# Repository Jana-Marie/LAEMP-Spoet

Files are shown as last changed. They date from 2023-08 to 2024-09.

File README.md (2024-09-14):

# LÄMP-Spöt

LÄMP-Spöt is an open source, multi-channel (multi-colour) LED spot that aims to deliver high quality effect-lighting through up to 6 LED-channels with ~10W each. This allows for a broader colour range than just RGB or RGBW, but RGB + non-mixed secondaries (i.e. RGB, Yellow, Cyan, Purple), RGB + Yellow + Whites, a variety of White tones (with degrees of Red, Blue and Green hues) and of course effect channels (i.e. UV, IR). In that, I have assembled various spöts that follow these suggestions, one that features RGBY + UV + IR, RGBY + IR + White and one with three channels of white + UV + IR for plants

<table>
	<tbody>
		<tr>
			<td>
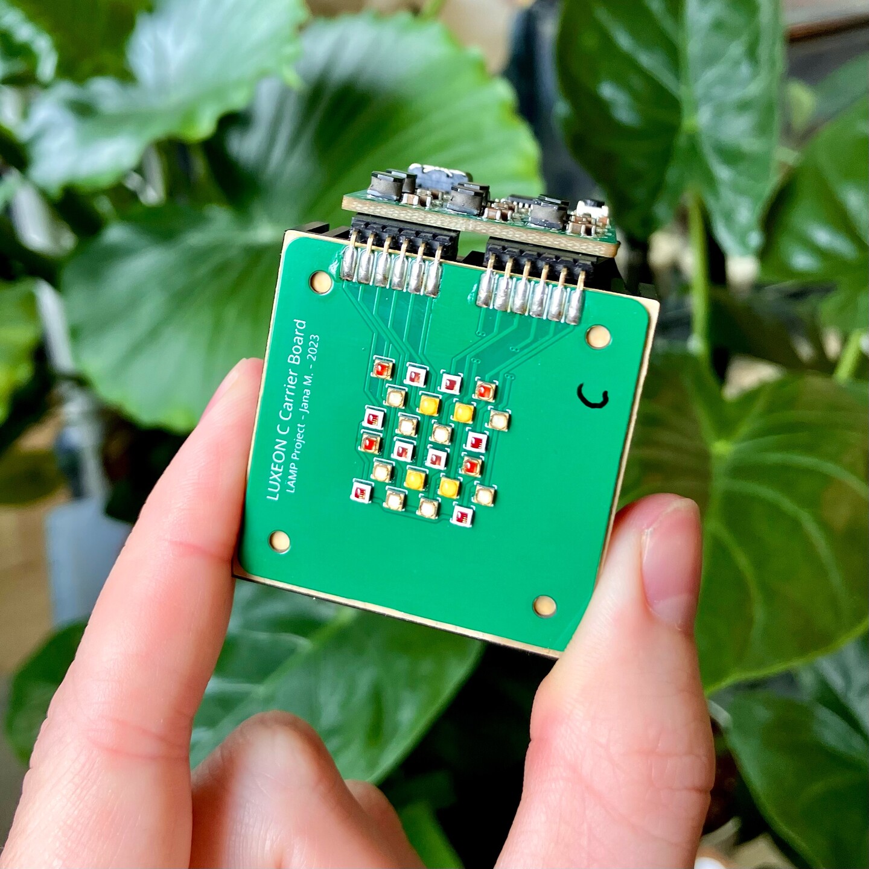
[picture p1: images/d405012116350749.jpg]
				
			</td>
			<td>
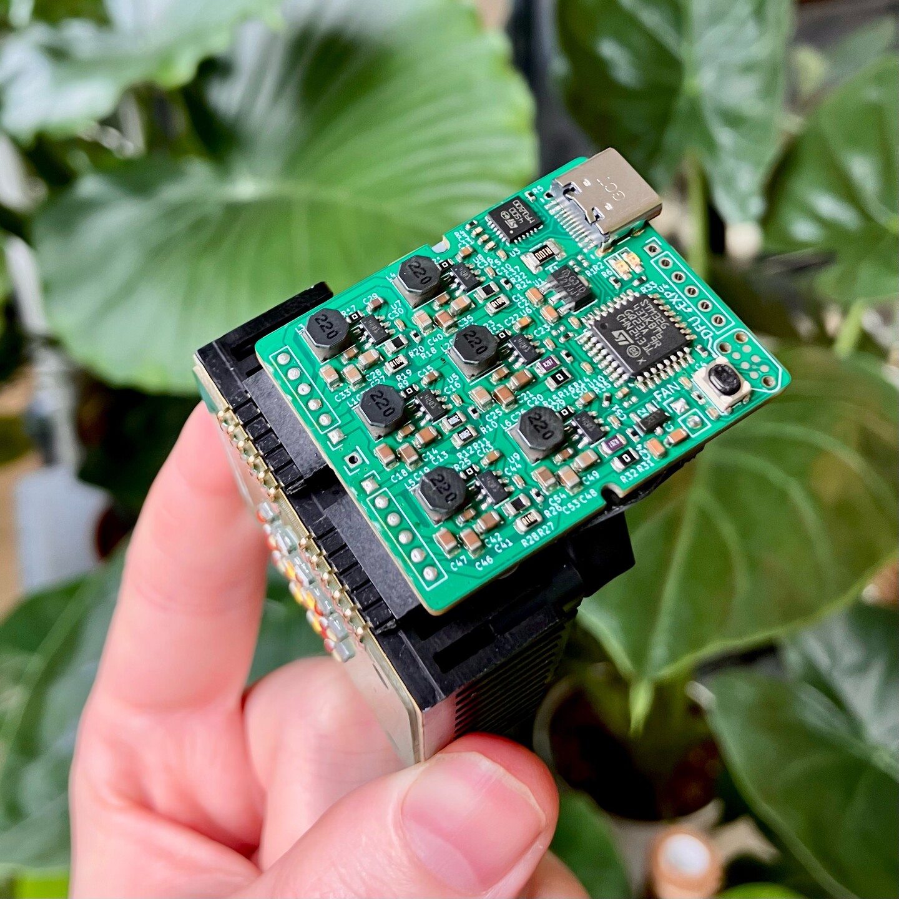
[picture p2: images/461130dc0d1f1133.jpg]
				
			</td>
		</tr>
	</tbody>
</table>

Each spöt consists of at least an LED carrier and a driver board. The driver-board is fairly generic, but can be optimized for each LED board by conforming the DCDC-Shunts to match the maximum LED current of that channel. You can of course set all channels to max current in hardware and use software-limiting. The LED carrier boards are a bit more specific due to their LED footprints. In addition you will probably want to sink the LEDs heat to somewhere, I've chosen "LA ICK 17x17" heatsinks from fisherelektronik.

You can find a [video of a preliminary board in action here.](https://chaos.social/@janamarie/110854704275031346)

It's not neccesarrily fixed on a single LED series by virtue of the LED-carrier being interchangable. I focused myself on using the Luxeon C series, it featurs a high variety of colours in the same package, as well as various binned whites. There is also a breakout board for a 6-Channel (RGBY, W, UV), single package led, available through chinese companies.

<a href="https://otmm.lumileds.com/adaptivemedia/f5fbe66cb9d857d62d895f92b8d6be3cc5919925">
	<table>
		<tbody>
			<tr>
				<td colspan="6">
					Available Lumileds Luxeon C Color Series measured and published by Lumileds (click me to assess the source)
				</td>
			</tr>
			<tr>
				<td colspan="3">
					
				</td>
				<td colspan="3">
					
				</td>
			</tr>
			<tr>
				<td colspan="6">
					Available Lumileds Luxeon C White Series measured and published by Lumileds (click me to assess the source)
				</td>
			</tr>
			<tr>
				<td colspan="2">
					
				</td>
				<td colspan="2">
					
				</td>
				<td colspan="2">
					
				</td>
			</tr>
		</tbody>
	</table>
</a>

The driver-board hosts an STM32G431 with a huge surplus in computing power, allowing for generous colour-space conversions and color-to-wavelength matching. None of this is implemented as of right now (~09-2024). It requires a 15-20V USB-PD source to run. The MCU speaks USB FS through the Type-C receptacle as well. A 2mm pinheader with power, signals and I2C allows for connectivity through shield-like addons (blame me for only having USB FS as on-board connectivity :/). Each channel features a TPS54201 CC Buck as analog-current-source allowing each channel to run at up to 1.5A @ 20V.

**Please do not reproduce this project if you are not willing to put some work and money into your reproduction, it's mechanical setup is highly alpha and there is little firmware.**

<table>
	<tbody>
		<tr>
			<td>
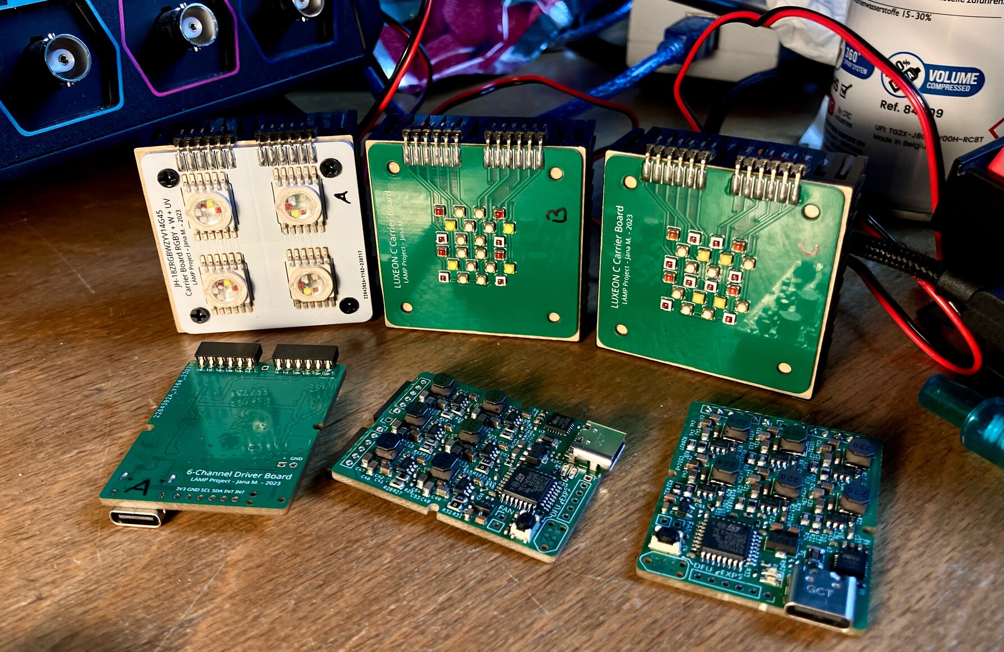
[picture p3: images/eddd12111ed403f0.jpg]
				
			</td>
			<td>
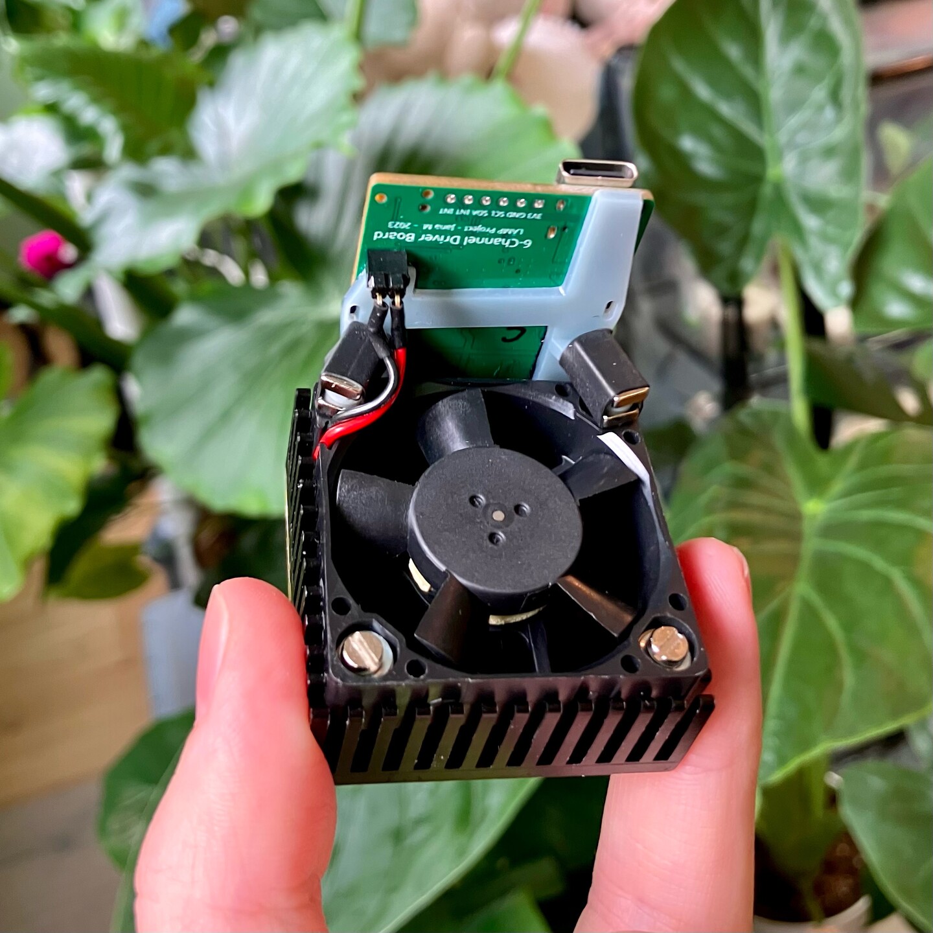
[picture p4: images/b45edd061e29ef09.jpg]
				
			</td>
		</tr>
	</tbody>
</table>

---

## Schematics

<a href="https://github.com/Jana-Marie/LAEMP-Spoet/tree/main/led-driver/schematic.pdf">
	<table>
		<tbody>
			<tr>
				<td colspan="2">
					Link to PDF
				</td>
			</tr>
			<tr>
				<td>
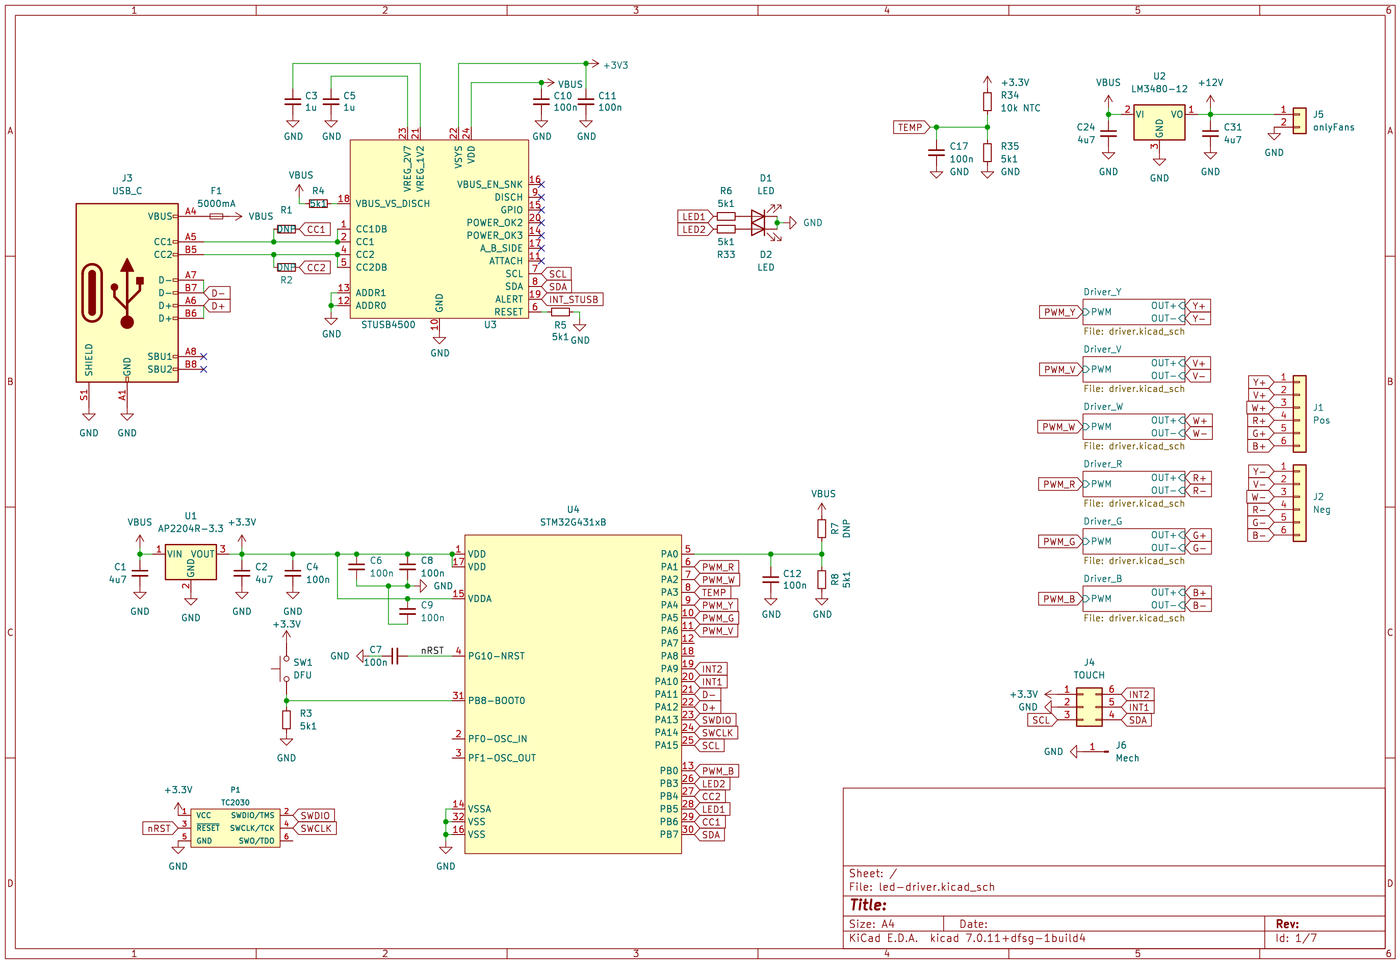
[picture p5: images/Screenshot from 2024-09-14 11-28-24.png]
					
				</td>
				<td>
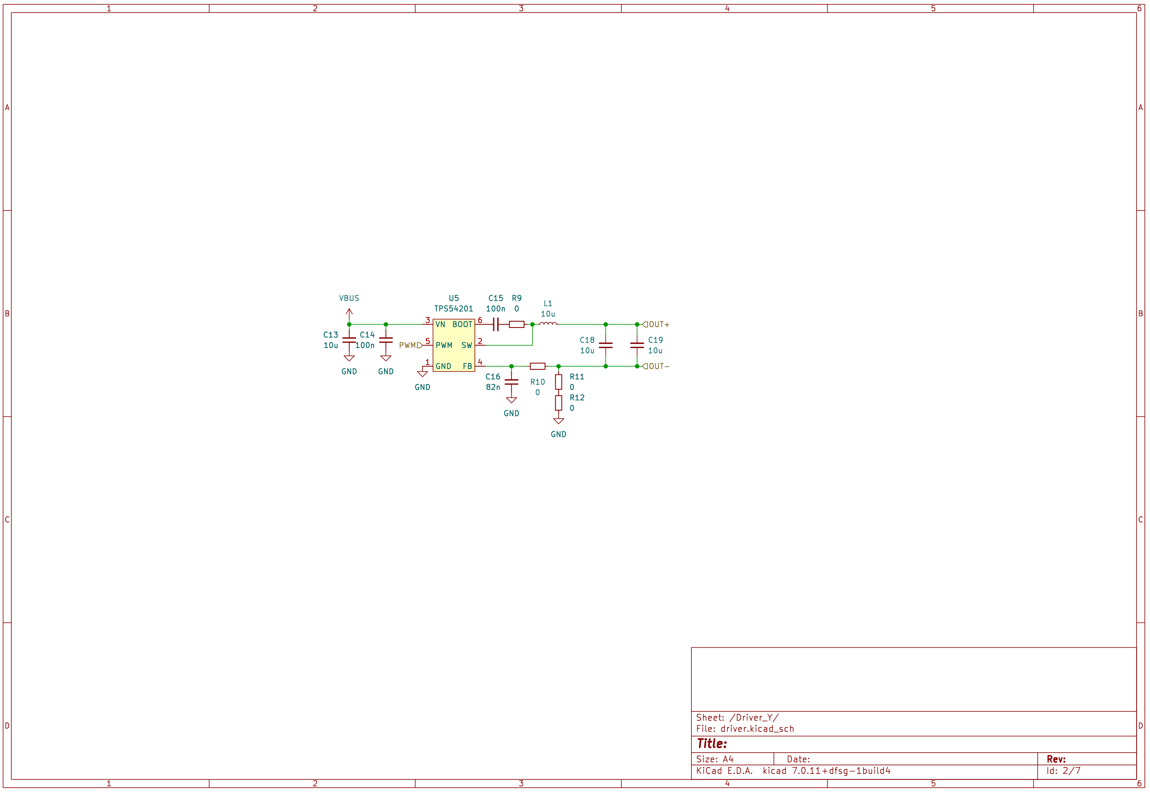
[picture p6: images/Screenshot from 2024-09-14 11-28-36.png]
					
				</td>
			</tr>
		</tbody>
	</table>
</a>

---

## Todos

 - [ ] Add a connectivity shield that allows for control via either DMX, Artnet or Other
 - [ ] Design a rigid case that features proper input jacks, a ¼ inch screw mount and proper cooling

### Bugs & PCB-enhancements

 - [ ] Improve cooling options
   - [ ] Connect the fan output to a PWM or enable
   - [ ] Add a temperature-probe for the fan

---

## License

Copyright Jana Marie Hemsing 2023.

This source describes Open Hardware and is licensed under the CERN-OHL-S v2.

You may redistribute and modify this source and make products using it under
the terms of the CERN-OHL-S v2 (https://ohwr.org/cern_ohl_s_v2.txt).

This source is distributed WITHOUT ANY EXPRESS OR IMPLIED WARRANTY,
INCLUDING OF MERCHANTABILITY, SATISFACTORY QUALITY AND FITNESS FOR A
PARTICULAR PURPOSE. Please see the CERN-OHL-S v2 for applicable conditions.

Source location: https://github.com/Jana-Marie/LAEMP-Spoet

As per CERN-OHL-S v2 section 4, should You produce hardware based on this
source, You must where practicable maintain the Source Location visible
on the external case of the Gizmo or other products you make using this
source.

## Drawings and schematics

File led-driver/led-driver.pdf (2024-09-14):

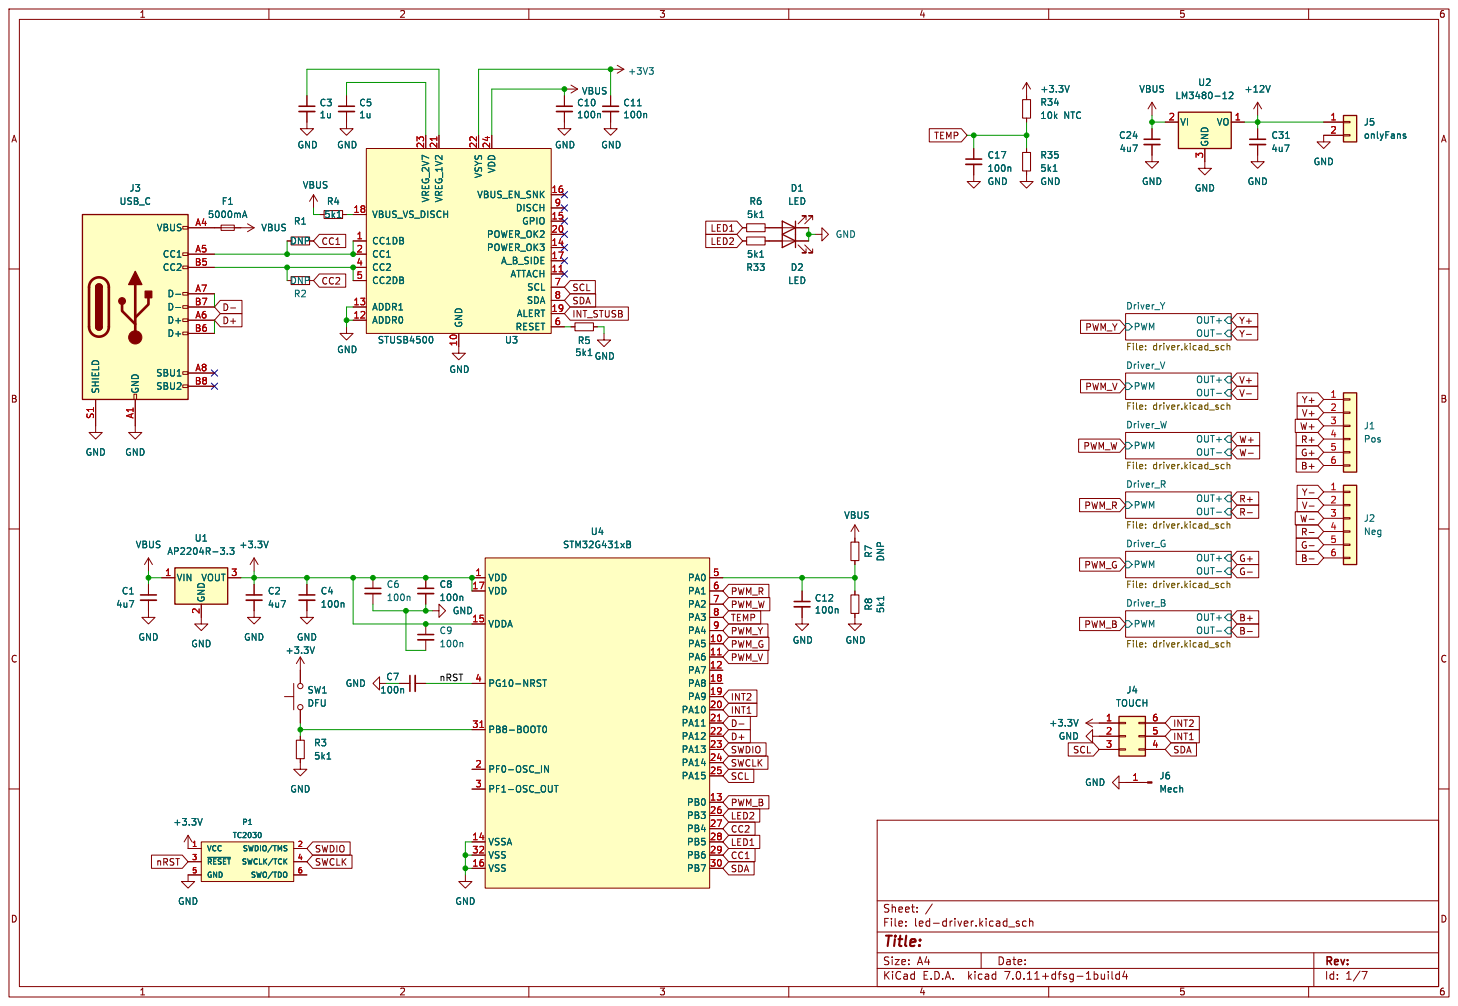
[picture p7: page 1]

Id: 1/7 Title: File: led-driver.kicad_sch Sheet: /

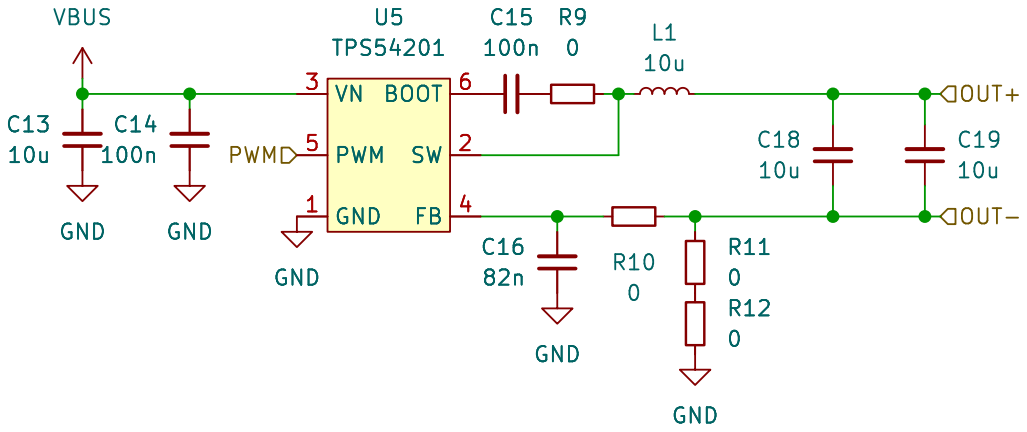
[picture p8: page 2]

Id: 2/7 Title: File: driver.kicad_sch Sheet: /Driver_Y/ R11

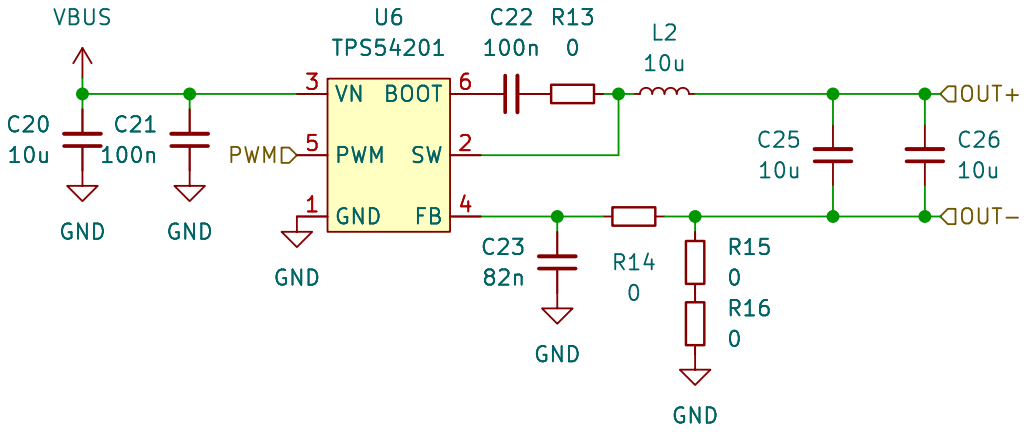
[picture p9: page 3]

Id: 3/7 Title: File: driver.kicad_sch Sheet: /Driver_V/ R16

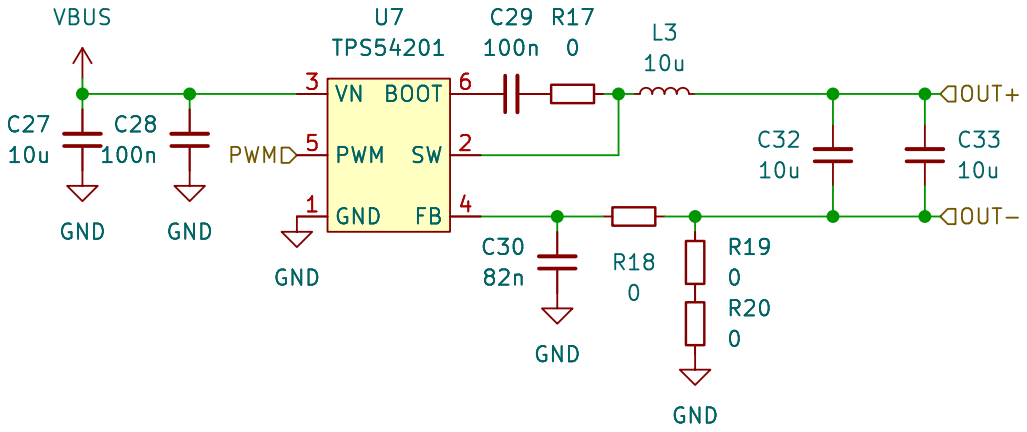
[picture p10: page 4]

Id: 4/7 Title: File: driver.kicad_sch Sheet: /Driver_W/ GND

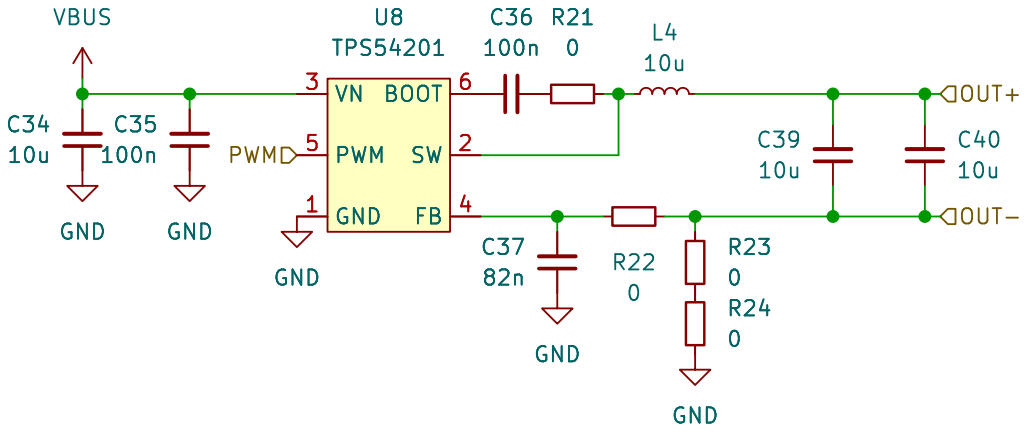
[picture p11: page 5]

Id: 5/7 Title: File: driver.kicad_sch Sheet: /Driver_R/ R23

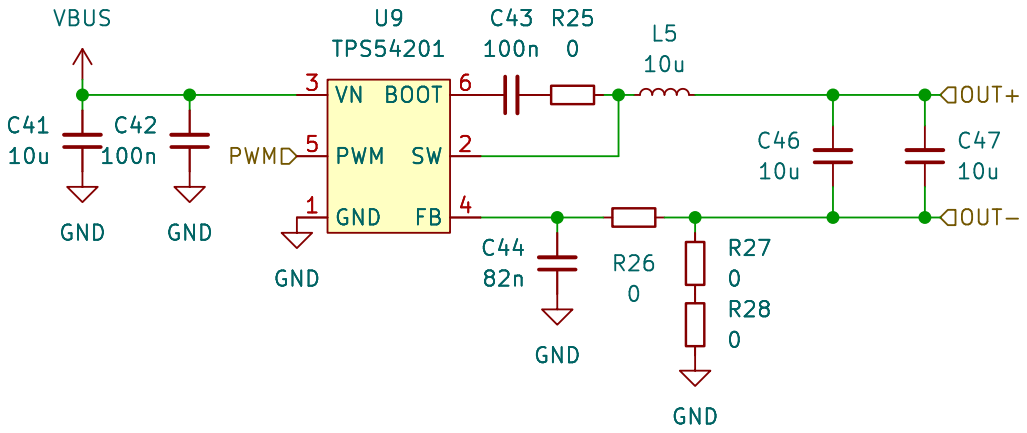
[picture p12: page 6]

Id: 6/7 Title: File: driver.kicad_sch Sheet: /Driver_G/ R28

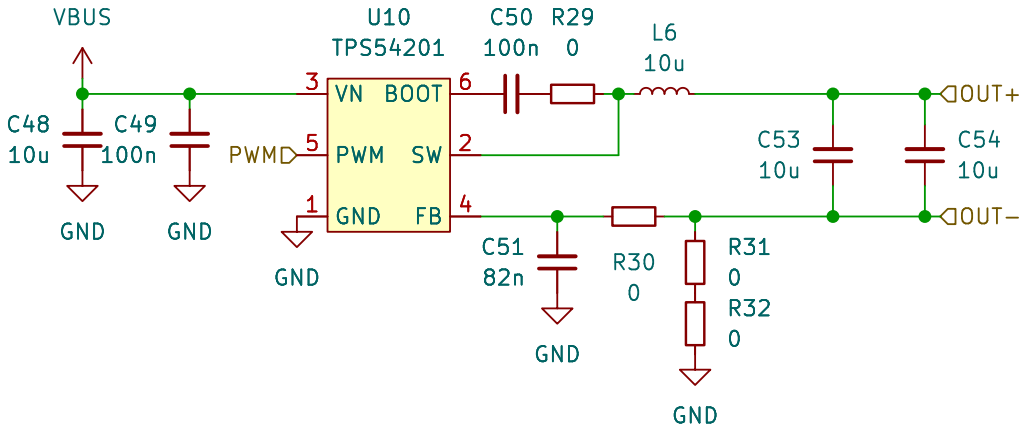
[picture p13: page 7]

Id: 7/7 Title: File: driver.kicad_sch Sheet: /Driver_B/ GND

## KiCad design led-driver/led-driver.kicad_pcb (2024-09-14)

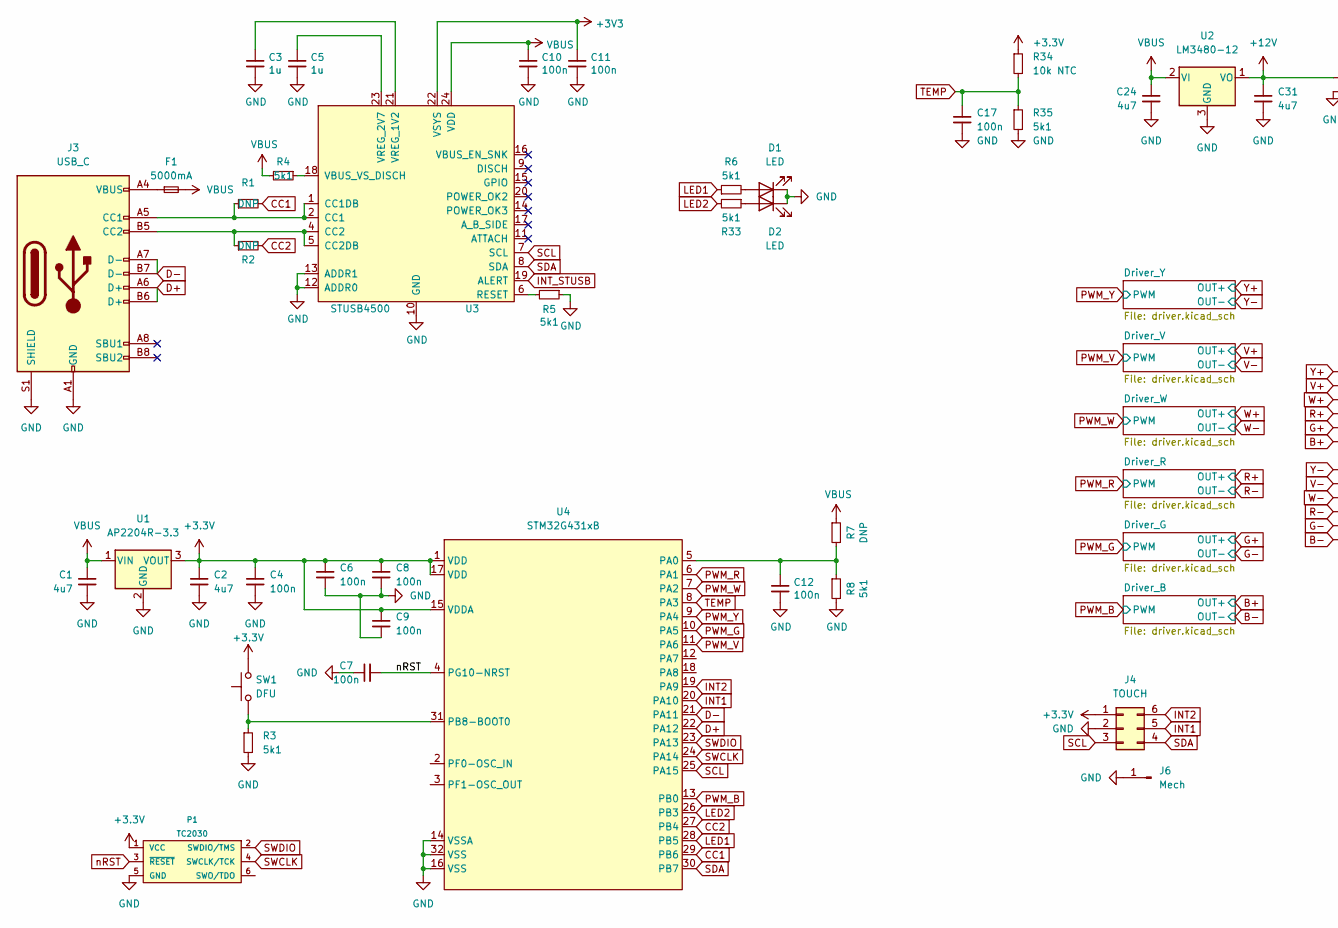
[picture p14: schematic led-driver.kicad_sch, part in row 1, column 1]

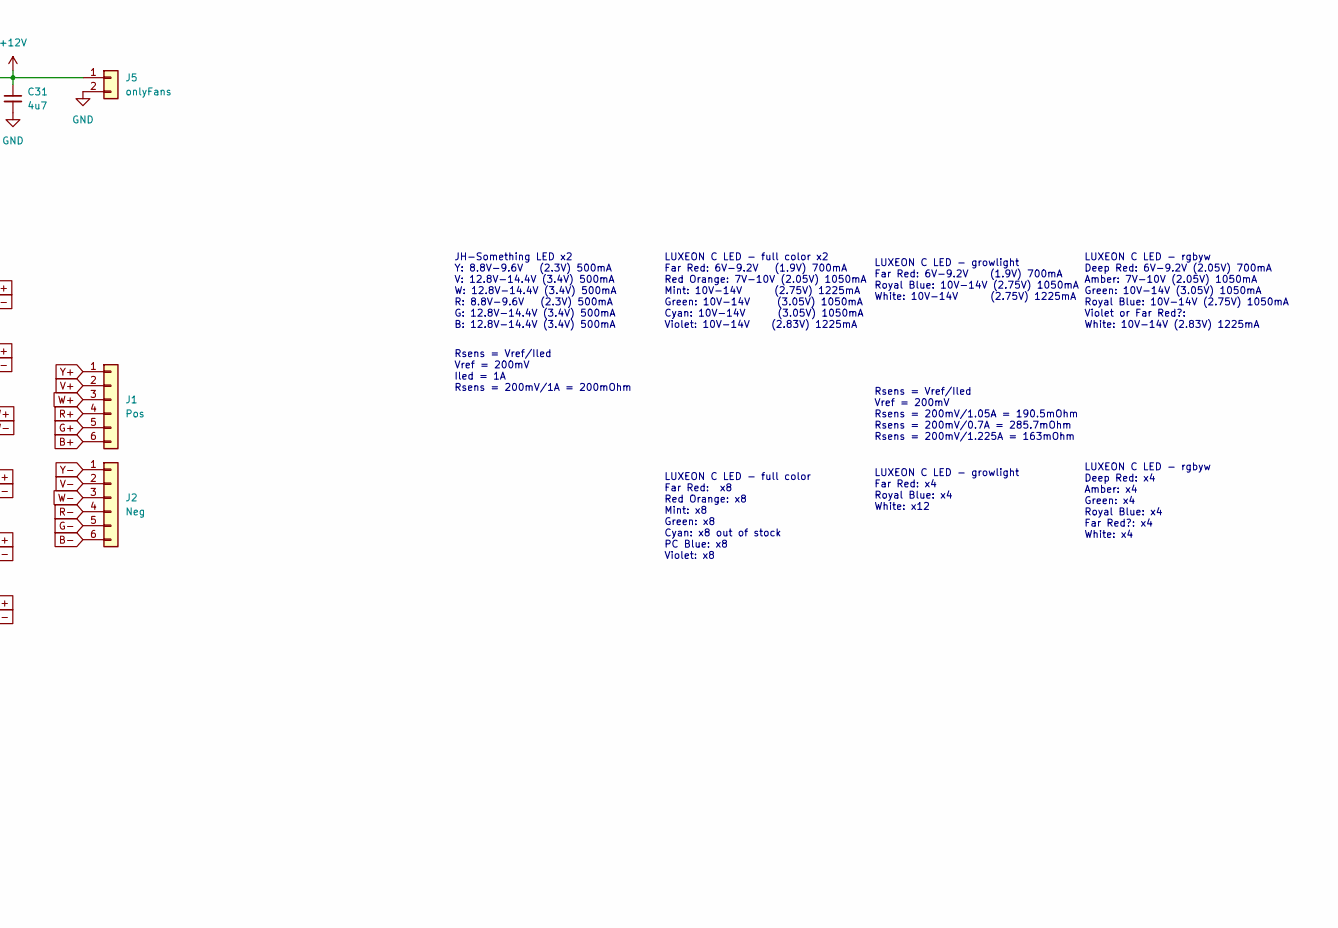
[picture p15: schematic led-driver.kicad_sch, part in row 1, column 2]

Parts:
C1, C2, C24, C31: 4u7; C_0603
C3, C5: 1u; C_0402
C4, C6, C7, C8, C9, C10, C11, C12, C17: 100n; C_0402
D1, D2: LED; LED_0603_1608Metric
F1: 5000mA; R_1210_3225Metric
J1: Pos; PinSocket_1x06_P2.00mm_Vertical_center
J2: Neg; PinSocket_1x06_P2.00mm_Vertical_center
J3: USB_C; USB-C 16Pin
J4: TOUCH; PinSocket_1x06_P2.00mm_Vertical_center
J5: onlyFans; PinHeader_1x02_P2.00mm_Vertical
J6: Mech; PinHeader_1x01_P2.00mm_Vertical
P1: TC2030
R1, R2, R7: DNP; R_0402
R3, R4, R5, R6, R8, R33, R35: 5k1; R_0402
R34: 10k NTC; R_0402
SW1: DFU; SW_SPST_PTS810
U1: AP2204R-3.3; SOT-89-3
U2: LM3480-12; SOT-23
U3: STUSB4500; QFN-24-1EP_4x4mm_P0.5mm_EP2.7x2.7mm
U4: STM32G431xB; LQFP-32_7x7mm_P0.8mm

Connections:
+12V: C31.1, J5.1, U2.1 (VO)
B+: J1.6; also elsewhere on the board
B-: J2.6; also elsewhere on the board
CC1: R1.2, U4.29 (PB6)
CC2: R2.2, U4.27 (PB4)
D+: J3.A6 (D+), J3.B6 (D+), U4.22 (PA12)
D-: J3.A7 (D-), J3.B7 (D-), U4.21 (PA11)
G+: J1.5; also elsewhere on the board
G-: J2.5; also elsewhere on the board
GND: C1.2, C2.2, C3.2, C4.2, C5.2, C6.2, C7.1, C8.2, C9.2, C10.2, C11.2, C12.2, C17.2, C24.2, C31.2, D1.1 (K), D2.1 (K), J3.A1 (GND), J3.A12 (GND), J3.B1 (GND), J3.B12 (GND), J3.S1 (SHIELD), J4.2, J5.2, J6.1, P1.5 (GND), R3.2, R5.1, R8.2, R35.2, U1.2 (GND), U2.3 (GND), U3.10 (GND), U3.12 (ADDR0), U3.13 (ADDR1), U3.25 (GND), U4.14 (VSSA), U4.16 (VSS), U4.32 (VSS); also elsewhere on the board
INT1: J4.5, U4.20 (PA10)
INT2: J4.6, U4.19 (PA9)
INT_STUSB: U3.19 (ALERT)
LED1: R6.1, U4.28 (PB5)
LED2: R33.2, U4.26 (PB3)
unnamed: D1.2 (A), R6.2
unnamed: D2.2 (A), R33.1
unnamed: F1.1, J3.A4 (VBUS), J3.A9 (VBUS), J3.B4 (VBUS), J3.B9 (VBUS)
unnamed: J3.A5 (CC1), R1.1, U3.1 (CC1DB), U3.2 (CC1)
unnamed: J3.B5 (CC2), R2.1, U3.4 (CC2), U3.5 (CC2DB)
unnamed: R5.2, U3.6 (RESET)
unnamed: R4.1, U3.18 (VBUS_VS_DISCH)
unnamed: C3.1, U3.21 (VREG_1V2)
unnamed: C5.1, U3.23 (VREG_2V7)
unnamed: C12.1, R7.2, R8.1, U4.5 (PA0)
unnamed: R3.1, SW1.1, U4.31 (PB8-BOOT0)
PWM_B: U4.13 (PB0); also elsewhere on the board
PWM_G: U4.10 (PA5); also elsewhere on the board
PWM_R: U4.6 (PA1); also elsewhere on the board
PWM_V: U4.11 (PA6); also elsewhere on the board
PWM_W: U4.7 (PA2); also elsewhere on the board
PWM_Y: U4.9 (PA4); also elsewhere on the board
R+: J1.4; also elsewhere on the board
R-: J2.4; also elsewhere on the board
SCL: J4.3, U3.7 (SCL), U4.25 (PA15)
SDA: J4.4, U3.8 (SDA), U4.30 (PB7)
SWCLK: P1.4 (SWCLK/TCK), U4.24 (PA14)
SWDIO: P1.2 (SWDIO/TMS), U4.23 (PA13)
TEMP: C17.1, R34.2, R35.1, U4.8 (PA3)
V+: J1.2; also elsewhere on the board
V-: J2.2; also elsewhere on the board
VBUS: C1.1, C10.1, C24.1, F1.2, R4.2, R7.1, U1.1 (VIN), U2.2 (VI), U3.24 (VDD); also elsewhere on the board
W+: J1.3; also elsewhere on the board
W-: J2.3; also elsewhere on the board
Y+: J1.1; also elsewhere on the board
Y-: J2.1; also elsewhere on the board
nRST: C7.2, P1.3 (~RESET), U4.4 (PG10-NRST)

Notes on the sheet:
Rsens = Vref/Iled Vref = 200mV Iled = 1A Rsens = 200mV/1A = 200mOhm
LUXEON C LED - rgbyw Deep Red: 6V-9.2V (2.05V) 700mA Amber: 7V-10V (2.05V) 1050mA Green: 10V-14V (3.05V) 1050mA Royal Blue: 10V-14V (2.75V) 1050mA Violet or Far Red?: White: 10V-14V (2.83V) 1225mA
LUXEON C LED - growlight Far Red: x4 Royal Blue: x4 White: x12
LUXEON C LED - rgbyw Deep Red: x4 Amber: x4 Green: x4 Royal Blue: x4 Far Red?: x4 White: x4
Rsens = Vref/Iled Vref = 200mV Rsens = 200mV/1.05A = 190.5mOhm Rsens = 200mV/0.7A = 285.7mOhm Rsens = 200mV/1.225A = 163mOhm
LUXEON C LED - full color Far Red: x8 Red Orange: x8 Mint: x8 Green: x8 Cyan: x8 out of stock PC Blue: x8 Violet: x8
LUXEON C LED - growlight Far Red: 6V-9.2V (1.9V) 700mA Royal Blue: 10V-14V (2.75V) 1050mA White: 10V-14V (2.75V) 1225mA
JH-Something LED x2 Y: 8.8V-9.6V (2.3V) 500mA V: 12.8V-14.4V (3.4V) 500mA W: 12.8V-14.4V (3.4V) 500mA R: 8.8V-9.6V (2.3V) 500mA G: 12.8V-14.4V (3.4V) 500mA B: 12.8V-14.4V (3.4V) 500mA
LUXEON C LED - full color x2 Far Red: 6V-9.2V (1.9V) 700mA Red Orange: 7V-10V (2.05V) 1050mA Mint: 10V-14V (2.75V) 1225mA Green: 10V-14V (3.05V) 1050mA Cyan: 10V-14V (3.05V) 1050mA Violet: 10V-14V (2.83V) 1225mA

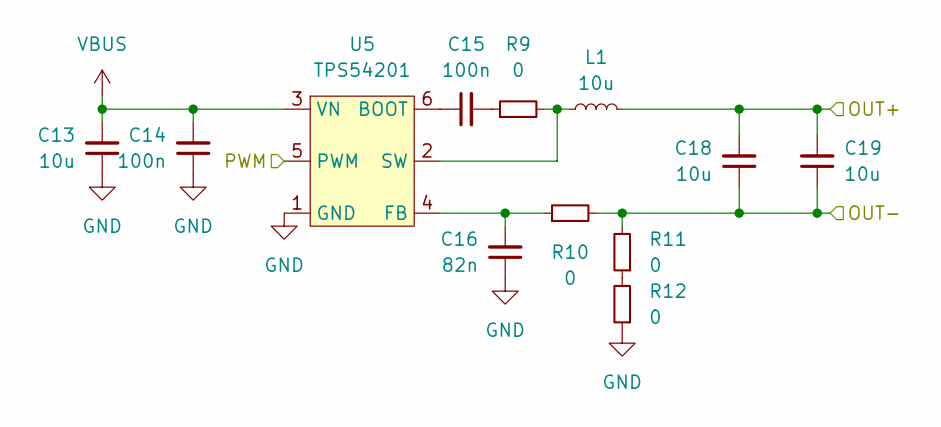
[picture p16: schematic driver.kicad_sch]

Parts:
C13, C18, C19: 10u; C_0805
C14, C15: 100n; C_0603
C16: 82n; C_0402
L1: 10u; L_Taiyo-Yuden_MD-4040
R9: 0; R_0603
R10: 0; R_0402
R11, R12: 0; R_0805
U5: TPS54201; SOT-23-6

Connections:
GND: C13.1, C14.1, C16.1, R12.1, U5.1 (GND); also elsewhere on the board
unnamed: C15.2, R9.1
unnamed: R11.1, R12.2
unnamed: C15.1, U5.6 (BOOT)
unnamed: C16.2, R10.1, U5.4 (FB)
unnamed: L1.1, R9.2, U5.2 (SW)
PWM_Y: U5.5 (PWM); also elsewhere on the board
VBUS: C13.2, C14.2, U5.3 (VN); also elsewhere on the board
Y+: C18.2, C19.2, L1.2; also elsewhere on the board
Y-: C18.1, C19.1, R10.2, R11.2; also elsewhere on the board

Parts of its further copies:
C20, C25, C26, C27, C32, C33, C34, C39, C40, C41, C46, C47, C48, C53, C54: 10u; C_0805
C21, C22, C28, C29, C35, C36, C42, C43, C49, C50: 100n; C_0603
C23, C30, C37, C44, C51: 82n; C_0402
L2, L3, L4, L5, L6: 10u; L_Taiyo-Yuden_MD-4040
R13, R17, R21, R25, R29: 0; R_0603
R14, R18, R22, R26, R30: 0; R_0402
R15, R16, R19, R20, R23, R24, R27, R28, R31, R32: 0; R_0805
U6, U7, U8, U9, U10: TPS54201; SOT-23-6

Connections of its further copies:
B+: C53.2, C54.2, L6.2; also elsewhere on the board
B-: C53.1, C54.1, R30.2, R31.2; also elsewhere on the board
G+: C46.2, C47.2, L5.2; also elsewhere on the board
G-: C46.1, C47.1, R26.2, R27.2; also elsewhere on the board
GND: C20.1, C21.1, C23.1, C27.1, C28.1, C30.1, C34.1, C35.1, C37.1, C41.1, C42.1, C44.1, C48.1, C49.1, C51.1, R16.1, R20.1, R24.1, R28.1, R32.1, U6.1 (GND), U7.1 (GND), U8.1 (GND), U9.1 (GND), U10.1 (GND); also elsewhere on the board
unnamed: C22.2, R13.1
unnamed: C29.2, R17.1
unnamed: C36.2, R21.1
unnamed: C43.2, R25.1
unnamed: C50.2, R29.1
unnamed: R15.1, R16.2
unnamed: R19.1, R20.2
unnamed: R23.1, R24.2
unnamed: R27.1, R28.2
unnamed: R31.1, R32.2
unnamed: C22.1, U6.6 (BOOT)
unnamed: C23.2, R14.1, U6.4 (FB)
unnamed: L2.1, R13.2, U6.2 (SW)
unnamed: C29.1, U7.6 (BOOT)
unnamed: C30.2, R18.1, U7.4 (FB)
unnamed: L3.1, R17.2, U7.2 (SW)
unnamed: C36.1, U8.6 (BOOT)
unnamed: C37.2, R22.1, U8.4 (FB)
unnamed: L4.1, R21.2, U8.2 (SW)
unnamed: C43.1, U9.6 (BOOT)
unnamed: C44.2, R26.1, U9.4 (FB)
unnamed: L5.1, R25.2, U9.2 (SW)
unnamed: C50.1, U10.6 (BOOT)
unnamed: C51.2, R30.1, U10.4 (FB)
unnamed: L6.1, R29.2, U10.2 (SW)
PWM_B: U10.5 (PWM); also elsewhere on the board
PWM_G: U9.5 (PWM); also elsewhere on the board
PWM_R: U8.5 (PWM); also elsewhere on the board
PWM_V: U6.5 (PWM); also elsewhere on the board
PWM_W: U7.5 (PWM); also elsewhere on the board
R+: C39.2, C40.2, L4.2; also elsewhere on the board
R-: C39.1, C40.1, R22.2, R23.2; also elsewhere on the board
V+: C25.2, C26.2, L2.2; also elsewhere on the board
V-: C25.1, C26.1, R14.2, R15.2; also elsewhere on the board
VBUS: C20.2, C21.2, C27.2, C28.2, C34.2, C35.2, C41.2, C42.2, C48.2, C49.2, U6.3 (VN), U7.3 (VN), U8.3 (VN), U9.3 (VN), U10.3 (VN); also elsewhere on the board
W+: C32.2, C33.2, L3.2; also elsewhere on the board
W-: C32.1, C33.1, R18.2, R19.2; also elsewhere on the board

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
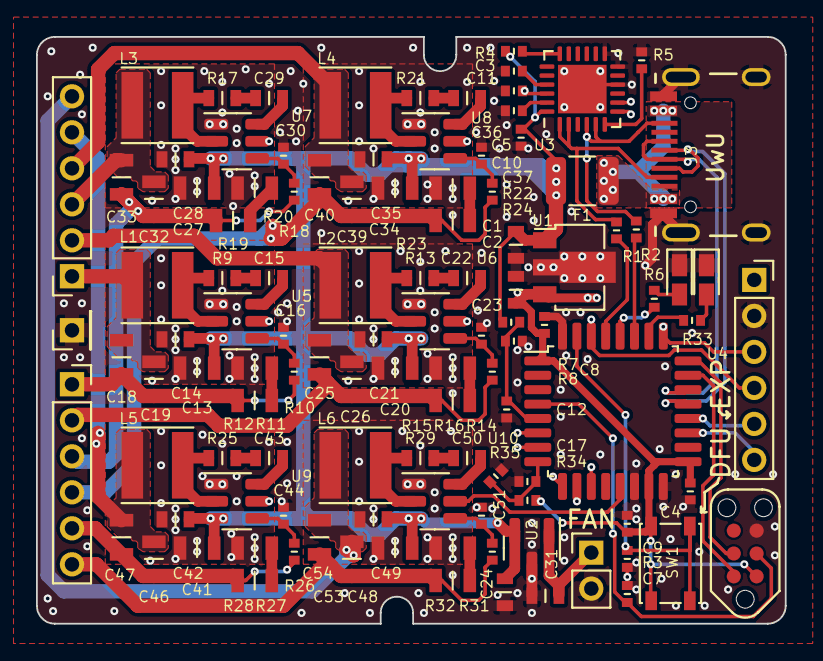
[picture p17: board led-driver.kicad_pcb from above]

Board: 4 copper layers, 41.6 x 32.6 mm, 112 parts (0 on the bottom side), 77 nets.

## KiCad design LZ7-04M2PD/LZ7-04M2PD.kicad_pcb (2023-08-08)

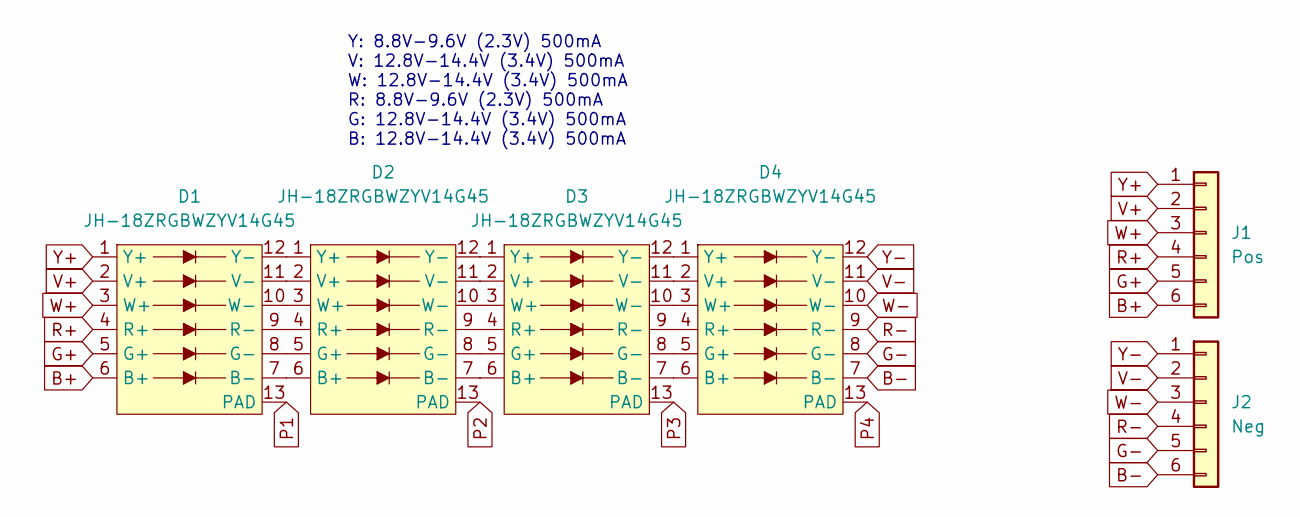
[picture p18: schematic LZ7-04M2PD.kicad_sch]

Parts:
D1, D2, D3, D4: JH-18ZRGBWZYV14G45
J1: Pos; CONN_1x06_SMD_SIDE
J2: Neg; CONN_1x06_SMD_SIDE

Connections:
B+: D1.6 (B+), J1.6
B-: D4.7 (B-), J2.6
G+: D1.5 (G+), J1.5
G-: D4.8 (G-), J2.5
unnamed: D1.7 (B-), D2.6 (B+)
unnamed: D1.8 (G-), D2.5 (G+)
unnamed: D1.9 (R-), D2.4 (R+)
unnamed: D1.10 (W-), D2.3 (W+)
unnamed: D1.11 (V-), D2.2 (V+)
unnamed: D1.12 (Y-), D2.1 (Y+)
unnamed: D2.7 (B-), D3.6 (B+)
unnamed: D2.8 (G-), D3.5 (G+)
unnamed: D2.9 (R-), D3.4 (R+)
unnamed: D2.10 (W-), D3.3 (W+)
unnamed: D2.11 (V-), D3.2 (V+)
unnamed: D2.12 (Y-), D3.1 (Y+)
unnamed: D3.7 (B-), D4.6 (B+)
unnamed: D3.8 (G-), D4.5 (G+)
unnamed: D3.9 (R-), D4.4 (R+)
unnamed: D3.10 (W-), D4.3 (W+)
unnamed: D3.11 (V-), D4.2 (V+)
unnamed: D3.12 (Y-), D4.1 (Y+)
P1: D1.13 (PAD)
P2: D2.13 (PAD)
P3: D3.13 (PAD)
P4: D4.13 (PAD)
R+: D1.4 (R+), J1.4
R-: D4.9 (R-), J2.4
V+: D1.2 (V+), J1.2
V-: D4.11 (V-), J2.2
W+: D1.3 (W+), J1.3
W-: D4.10 (W-), J2.3
Y+: D1.1 (Y+), J1.1
Y-: D4.12 (Y-), J2.1

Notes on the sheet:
Y: 8.8V-9.6V (2.3V) 500mA V: 12.8V-14.4V (3.4V) 500mA W: 12.8V-14.4V (3.4V) 500mA R: 8.8V-9.6V (2.3V) 500mA G: 12.8V-14.4V (3.4V) 500mA B: 12.8V-14.4V (3.4V) 500mA

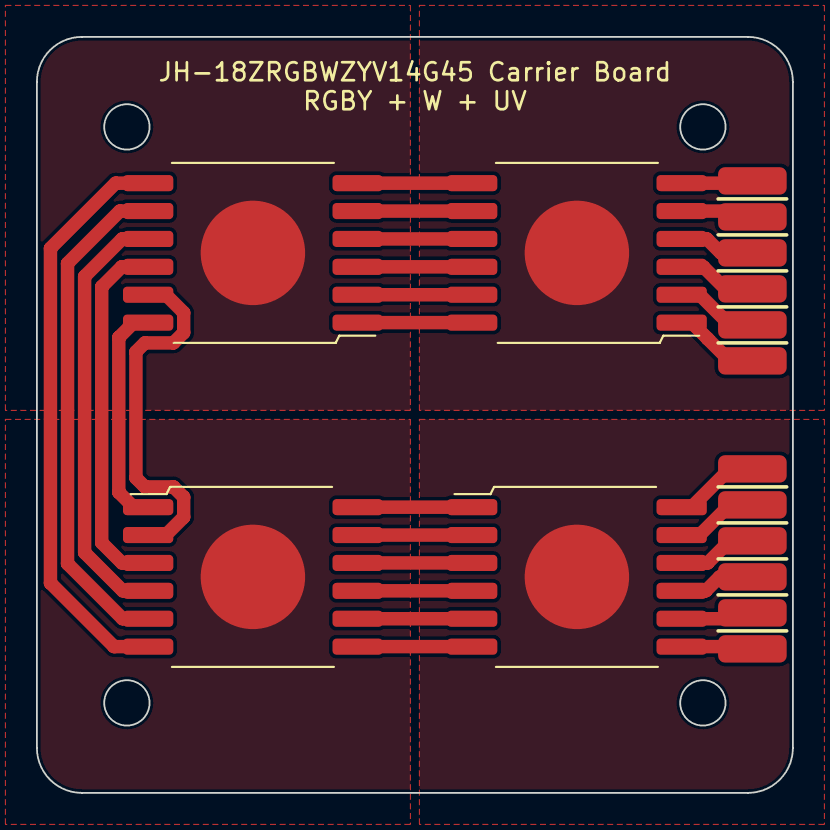
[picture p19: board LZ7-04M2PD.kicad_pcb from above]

Board: 2 copper layers, 42.0 x 42.0 mm, 6 parts (0 on the bottom side), 30 nets.

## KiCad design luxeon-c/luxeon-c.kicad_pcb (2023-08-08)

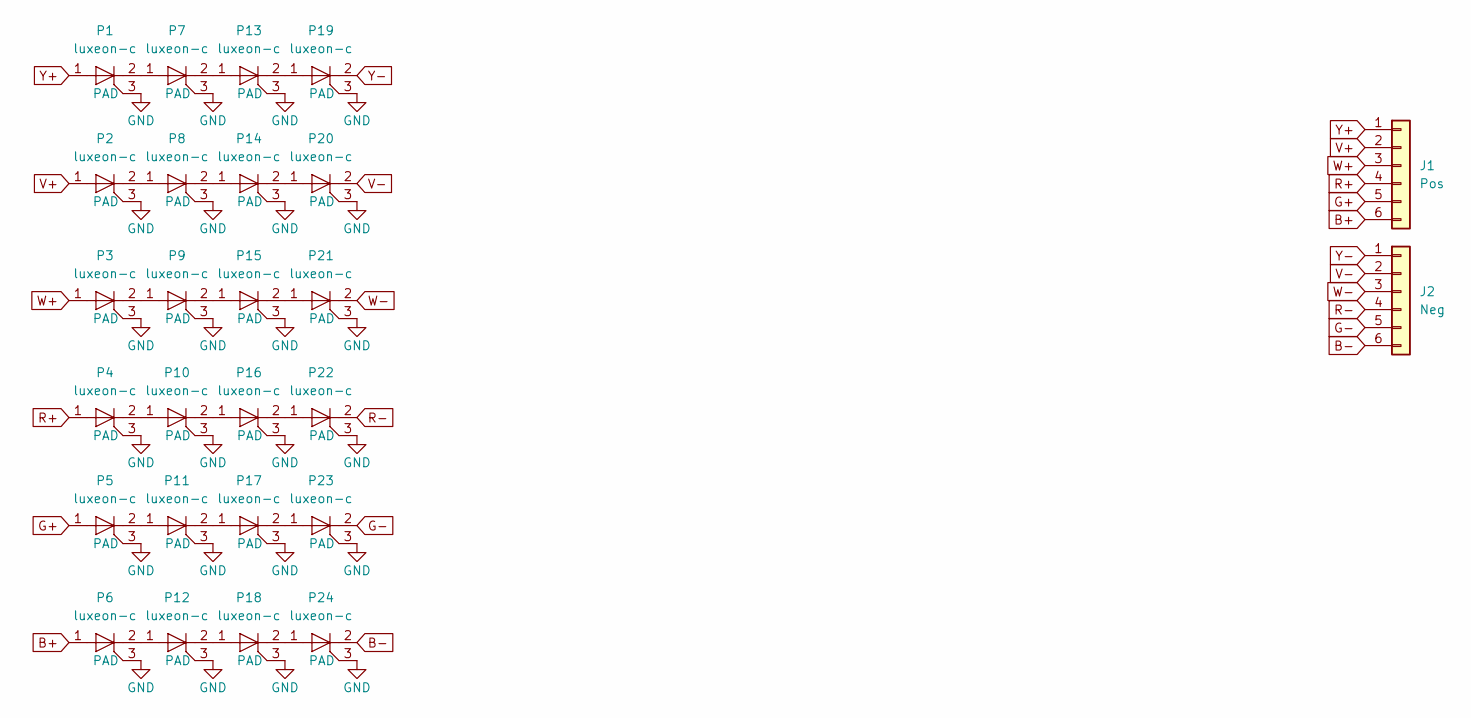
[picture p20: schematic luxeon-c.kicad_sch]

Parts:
J1: Pos; CONN_1x06_SMD_SIDE
J2: Neg; CONN_1x06_SMD_SIDE
P1, P2, P3, P4, P5, P6, P7, P8, P9, P10, P11, P12, P13, P14, P15, P16, P17, P18, P19, P20, P21, P22, P23, P24: luxeon-c

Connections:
B+: J1.6, P6.1
B-: J2.6, P24.2
G+: J1.5, P5.1
G-: J2.5, P23.2
GND: P1.3 (PAD), P2.3 (PAD), P3.3 (PAD), P4.3 (PAD), P5.3 (PAD), P6.3 (PAD), P7.3 (PAD), P8.3 (PAD), P9.3 (PAD), P10.3 (PAD), P11.3 (PAD), P12.3 (PAD), P13.3 (PAD), P14.3 (PAD), P15.3 (PAD), P16.3 (PAD), P17.3 (PAD), P18.3 (PAD), P19.3 (PAD), P20.3 (PAD), P21.3 (PAD), P22.3 (PAD), P23.3 (PAD), P24.3 (PAD)
unnamed: P1.2, P7.1
unnamed: P2.2, P8.1
unnamed: P3.2, P9.1
unnamed: P4.2, P10.1
unnamed: P10.2, P16.1
unnamed: P5.2, P11.1
unnamed: P11.2, P17.1
unnamed: P6.2, P12.1
unnamed: P12.2, P18.1
unnamed: P7.2, P13.1
unnamed: P13.2, P19.1
unnamed: P8.2, P14.1
unnamed: P14.2, P20.1
unnamed: P9.2, P15.1
unnamed: P15.2, P21.1
unnamed: P16.2, P22.1
unnamed: P17.2, P23.1
unnamed: P18.2, P24.1
R+: J1.4, P4.1
R-: J2.4, P22.2
V+: J1.2, P2.1
V-: J2.2, P20.2
W+: J1.3, P3.1
W-: J2.3, P21.2
Y+: J1.1, P1.1
Y-: J2.1, P19.2

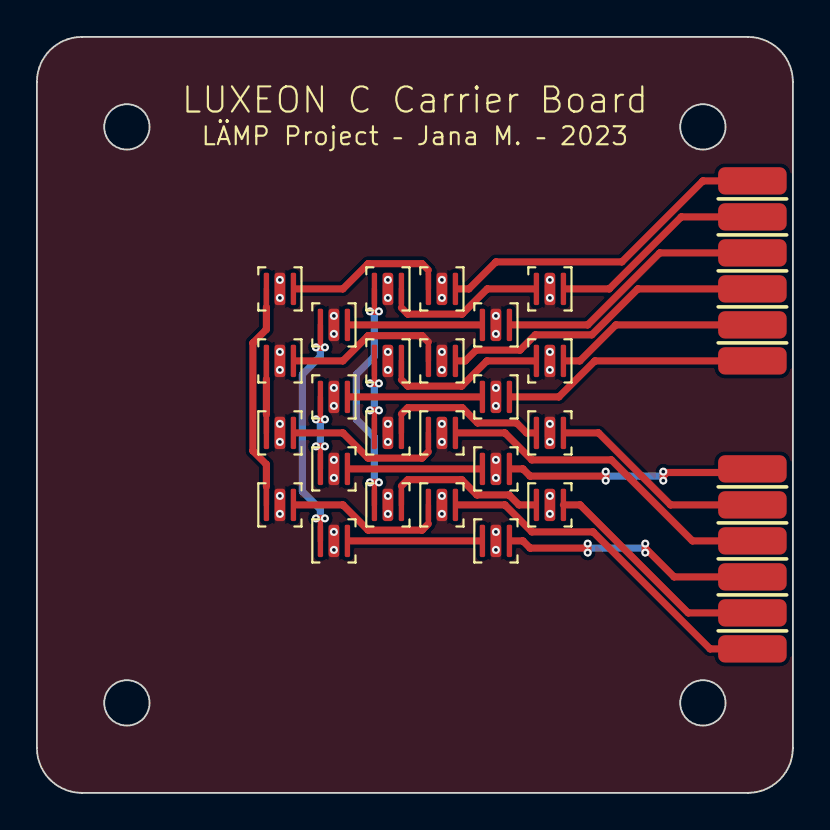
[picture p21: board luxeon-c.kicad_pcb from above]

Board: 2 copper layers, 42.0 x 42.0 mm, 26 parts (0 on the bottom side), 31 nets.

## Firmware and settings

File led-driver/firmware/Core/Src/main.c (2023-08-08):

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
/* Includes ------------------------------------------------------------------*/
#include "main.h"
#include "usb_device.h"

/* USER CODE BEGIN Includes */
#define PRESCALE 0
#define PERIOD 1000

uint16_t sine[256] = {0x32,0x34,0x37,0x39,0x3c,0x3e,0x41,0x43,0x45,0x48,0x4a,0x4c,0x4e,0x50,0x52,0x54,
0x56,0x57,0x59,0x5a,0x5c,0x5d,0x5e,0x5f,0x60,0x61,0x62,0x63,0x63,0x64,0x64,0x64,
0x64,0x64,0x64,0x63,0x63,0x62,0x62,0x61,0x60,0x5f,0x5e,0x5c,0x5b,0x5a,0x58,0x56,
0x55,0x53,0x51,0x4f,0x4d,0x4b,0x49,0x46,0x44,0x42,0x3f,0x3d,0x3b,0x38,0x36,0x33,
0x31,0x2e,0x2c,0x29,0x27,0x25,0x22,0x20,0x1e,0x1b,0x19,0x17,0x15,0x13,0x11,0xf,
0xe,0xc,0xa,0x9,0x8,0x6,0x5,0x4,0x3,0x2,0x2,0x1,0x1,0x0,0x0,0x0,
0x0,0x0,0x0,0x0,0x0,0x0,0x0,0x0,0x0,0x0,0x0,0x0,0x0,0x0,0x0,0x0,0x0,0x0,0x0,0x0,
0x0,0x0,0x0,0x0,0x0,0x0,0x0,0x0,0x0,0x0,0x0,0x0,0x0,0x0,0x0,0x0,0x0,0x0,0x0,0x0,
0x0,0x0,0x0,0x0,0x0,0x0,0x0,0x0,0x0,0x0,0x0,0x0,0x0,0x0,0x0,0x0,0x0,0x0,0x0,0x0,
0x0,0x0,0x0,0x0,0x0,0x0,0x0,0x0,0x0,0x0,0x0,0x0,0x0,0x0,0x0,0x0,0x0,0x0,0x0,0x0,
0x0,0x0,0x0,0x0,0x0,0x0,0x0,0x0,0x0,0x0,0x0,0x0,0x0,0x0,0x0,0x0,0x0,0x0,0x0,0x0,
0x0,0x0,0x0,0x0,0x0,0x0,0x0,0x0,0x0,0x0,0x0,0x0,0x0,0x0,0x0,0x0,0x0,0x0,0x0,0x0,
0x0,0x0,0x0,0x0,0x0,0x0,0x0,
0x0,0x0,0x0,0x1,0x1,0x2,0x3,0x4,0x5,0x6,0x7,0x8,0xa,0xb,0xd,0xe,
0x10,0x12,0x14,0x16,0x18,0x1a,0x1c,0x1f,0x21,0x23,0x26,0x28,0x2b,0x2d,0x30,0x32};
/* USER CODE END Includes */

ADC_HandleTypeDef hadc1;
DMA_HandleTypeDef hdma_adc1;

I2C_HandleTypeDef hi2c1;

TIM_HandleTypeDef htim2;
TIM_HandleTypeDef htim3;

void SystemClock_Config(void);
static void MX_GPIO_Init(void);
static void MX_DMA_Init(void);
static void MX_ADC1_Init(void);
static void MX_I2C1_Init(void);
static void MX_TIM2_Init(void);
static void MX_TIM3_Init(void);
/* USER CODE BEGIN 0 */
uint8_t i = 0;
/* USER CODE END 0 */

/**
  * @brief  The application entry point.
  * @retval int
  */
int main(void)
{
  /* MCU Configuration--------------------------------------------------------*/

  /* Reset of all peripherals, Initializes the Flash interface and the Systick. */
  HAL_Init();

  /* Configure the system clock */
  SystemClock_Config();

  /* Initialize all configured peripherals */
  MX_GPIO_Init();
  MX_DMA_Init();
  MX_ADC1_Init();
  MX_I2C1_Init();
  MX_TIM2_Init();
  MX_TIM3_Init();
  MX_USB_Device_Init();
  /* USER CODE BEGIN 2 */
  HAL_GPIO_WritePin(GPIOB, LED_POWER_Pin, 1);
  HAL_GPIO_WritePin(GPIOB, LED_STATUS_Pin, 1);

  HAL_Delay(100);
  
  HAL_GPIO_TogglePin(GPIOB, LED_STATUS_Pin);

  HAL_TIM_PWM_Start(&htim2, TIM_CHANNEL_1);
  HAL_TIM_PWM_Start(&htim2, TIM_CHANNEL_2);
  HAL_TIM_PWM_Start(&htim2, TIM_CHANNEL_3);
  HAL_TIM_PWM_Start(&htim3, TIM_CHANNEL_1);
  HAL_TIM_PWM_Start(&htim3, TIM_CHANNEL_2);
  HAL_TIM_PWM_Start(&htim3, TIM_CHANNEL_3);

  __HAL_TIM_SET_COMPARE(&htim2, TIM_CHANNEL_1, 750);
  HAL_Delay(1);
  __HAL_TIM_SET_COMPARE(&htim2, TIM_CHANNEL_1, 1);

  __HAL_TIM_SET_COMPARE(&htim2, TIM_CHANNEL_2, 750);
  HAL_Delay(1);
  __HAL_TIM_SET_COMPARE(&htim2, TIM_CHANNEL_2, 1);

  __HAL_TIM_SET_COMPARE(&htim2, TIM_CHANNEL_3, 750);
  HAL_Delay(1);
  __HAL_TIM_SET_COMPARE(&htim2, TIM_CHANNEL_3, 1);

  __HAL_TIM_SET_COMPARE(&htim3, TIM_CHANNEL_1, 750);
  HAL_Delay(1);
  __HAL_TIM_SET_COMPARE(&htim3, TIM_CHANNEL_1, 1);

  __HAL_TIM_SET_COMPARE(&htim3, TIM_CHANNEL_2, 750);
  HAL_Delay(1);
  __HAL_TIM_SET_COMPARE(&htim3, TIM_CHANNEL_2, 1);

  __HAL_TIM_SET_COMPARE(&htim3, TIM_CHANNEL_3, 750);
  HAL_Delay(1);
  __HAL_TIM_SET_COMPARE(&htim3, TIM_CHANNEL_3, 1);

  HAL_GPIO_TogglePin(GPIOB, LED_STATUS_Pin);
  /* USER CODE END 2 */

  /* Infinite loop */
  /* USER CODE BEGIN WHILE */
  while (1)
  {
    /* USER CODE END WHILE */
    __HAL_TIM_SET_COMPARE(&htim2, TIM_CHANNEL_1, sine[(i+(42*0)) % 255]);
    __HAL_TIM_SET_COMPARE(&htim2, TIM_CHANNEL_2, sine[(i+(42*1)) % 255]);
    __HAL_TIM_SET_COMPARE(&htim2, TIM_CHANNEL_3, sine[(i+(42*2)) % 255]);
    __HAL_TIM_SET_COMPARE(&htim3, TIM_CHANNEL_1, sine[(i+(42*3)) % 255]);
    __HAL_TIM_SET_COMPARE(&htim3, TIM_CHANNEL_2, sine[(i+(42*4)) % 255]);
    __HAL_TIM_SET_COMPARE(&htim3, TIM_CHANNEL_3, sine[(i+(42*5)) % 255]);
    i++;
    if (i > 254){
      i = 0;
    }

    HAL_Delay(80);

    HAL_GPIO_TogglePin(GPIOB, LED_STATUS_Pin);

    /* USER CODE BEGIN 3 */
  }
  /* USER CODE END 3 */
}

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


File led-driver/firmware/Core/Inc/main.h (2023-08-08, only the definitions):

#define LED_POWER_Pin GPIO_PIN_3
#define LED_POWER_GPIO_Port GPIOB
#define LED_STATUS_Pin GPIO_PIN_5
#define LED_STATUS_GPIO_Port GPIOB
#define DFU_IN_Pin GPIO_PIN_8
#define DFU_IN_GPIO_Port GPIOB

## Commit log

2023-08-08 added led driver
    [driver.kicad_sch, led-driver.kicad_pcb, led-driver.kicad_sch]
2023-08-08 added luxeon-c board
    [luxeon-c.kicad_pcb, luxeon-c.kicad_sch]
2023-08-08 added JH board
    [JH-18ZRGBWZYV14G45.kicad_pcb, JH-18ZRGBWZYV14G45.kicad_sch]
2023-08-08 added LZ7 board, untested!
    [LZ7-04M2PD.kicad_pcb, LZ7-04M2PD.kicad_sch]
2024-09-14 added schematic files
    [led-driver.kicad_pcb]

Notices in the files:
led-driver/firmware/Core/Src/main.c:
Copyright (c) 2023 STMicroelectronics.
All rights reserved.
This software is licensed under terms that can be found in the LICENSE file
